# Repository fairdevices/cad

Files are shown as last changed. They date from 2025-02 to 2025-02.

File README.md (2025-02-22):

# Faidevices CAD Repository

The Fairdevices project aims to make household appliances repairable. To achieve this, we are currently developing a universal control board for washing machines that is compatible with as many common devices as possible. This repository manages all source files for the washing machine control and documentation.
Status

## Status

The Project is actively maintained and the development is still in a very early stage. Currently, we are focusing on the development of:

- the power supply
- the heating control

## Licensing

The project is licensed under CERN-OHL-S-2.0. All files can be freely used, modified, and republished. The use of the Fairdevices name and logo is reserved for us.

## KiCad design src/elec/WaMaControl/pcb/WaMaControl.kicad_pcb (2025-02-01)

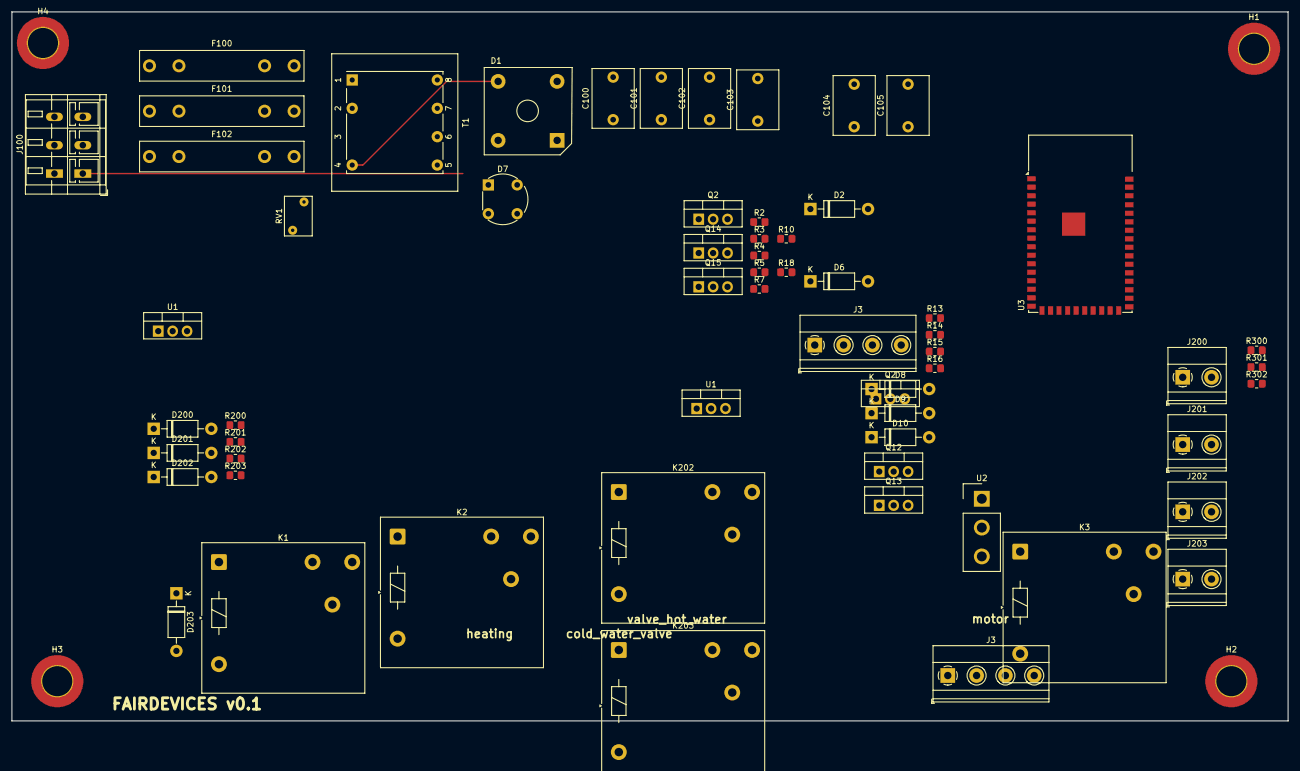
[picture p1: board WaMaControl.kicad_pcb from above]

Board: 2 copper layers, 225.0 x 125.0 mm, 66 parts (0 on the bottom side), 28 nets.

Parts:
C100, C101, C102, C103, C104, C105: C; C_Rect_L10.3mm_W7.2mm_P7.50mm_MKS4
D1: D_Bridge_+-AA; Diode_Bridge_Vishay_KBPC6
D2, D6, D8, D9, D10, D200, D201, D202, D203: 1N4001; D_DO-41_SOD81_P10.16mm_Horizontal
D7: D_Bridge_+-AA; Diode_Bridge_Round_D8.9mm
F100, F101, F102: Fuse; Fuseholder_Littelfuse_445_030_series_5x25mm
H1, H2, H3, H4: MountingHole; MountingHole_5.3mm_M5_DIN965_Pad_TopBottom
J3, J3#2: Conn_01x04_Female; TerminalBlock_Phoenix_MKDS-1,5-4-5.08_1x04_P5.08mm_Horizont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
J100: Conn_01x03_Female; TerminalBlock_WAGO_236-403_1x03_P5.00mm_45Degree
J200, J201, J202, J203: Conn_01x02_Female; TerminalBlock_Phoenix_MKDS-1,5-2-5.08_1x02_P5.08mm_Horizont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
K1, K2: Relay_SPDT; Relay_SPDT_Finder_40.11
K3, K202, K203: AZ850-x; Relay_SPDT_Finder_40.11
Q2, Q2#2, Q12, Q13, Q14: TIC126; TO-220-3_Vertical
Q15: BT138-600; TO-220-3_Vertical
R2, R3, R4, R5, R7, R10, R13, R14, R15, R16, R18, R200, R201, R202, R203, R300, R301, R302: R_Small; R_0805_2012Metric_Pad1.20x1.40mm_HandSolder
RV1: Varistor; RV_Disc_D7mm_W4.9mm_P5mm
T1: Transformer_1P_1S; Transformer_Breve_TEZ-22x24
U1, U1#2: LF50_TO220; TO-220-3_Vertical
U2: logo_fairdevices; Samtec_HPM-03-01-x-S_Straight_1x03_Pitch5.08mm
U3: ESP32-S2-WROVER

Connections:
+3.3V: C104.1, C105.1, R302.1, U1.3 (VO), U1#2.3 (VO), U3.2 (3V3)
+12V: C100.1, C101.1, C102.1, C103.1, D1.1 (+), D2.1 (K), D6.1 (K), D8.1 (K), D9.1 (K), D10.1 (K), D200.1 (K), D201.1 (K), D202.1 (K), D203.1 (K), K1.A1, K2.A1, U1.1 (VI), U1#2.1 (VI)
AC/L: F100.2, K1.14, K2.14, RV1.1, T1.1 (AA)
AC/N: J3.3, J3#2.3, J100.2, J200.2, J201.2, J202.1, RV1.2, T1.2 (AB)
CNTL-coldh2o: R200.1, U3.10 (IO07)
CNTL-drainpump: R203.1, U3.14 (IO11)
CNTL-heating: R202.1, U3.19 (IO16)
CNTR-warmh2o: R201.1, U3.11 (IO08)
Earth_Protective: C100.2, C101.2, C102.2, C103.2, C104.2, C105.2, D1.2 (-), D7.2 (-), J100.1, R10.1, R16.1, R301.2, U1.2 (GND), U1#2.2 (GND), U3.1 (GND), U3.26 (GND), U3.42 (GND), U3.43 (GND)
unnamed: D7.1 (+), R300.1
unnamed: D200.2 (A), K1.A2
unnamed: D201.2 (A), K2.A2
unnamed: F100.1, F101.1, F102.1, J100.3
unnamed: Q2.2 (A), Q2#2.2 (A)
unnamed: Q2.3 (G), Q2#2.3 (G)
unnamed: Q12.2 (A), Q13.1 (K)
unnamed: Q2.1 (K), Q2#2.1 (K), Q14.2 (A)
unnamed: Q15.2 (A2), R4.2
unnamed: Q15.3 (G), R2.1
Trafo-Sek-1: D1.3, D7.3, D7.4, T1.4 (SB)
coldwatervalve2: J200.1, K1.11
freq: R300.2, R301.1, U3.5 (IO02)
heating1: J202.2, Q14.1 (K), Q15.1 (A1), R2.2, R3.1
hotwatervalve2: J201.1, K2.11
motor1: J3.4, J3#2.4, Q12.1 (K)
motorsensor1: J3.2, J3#2.2
motorsensor2: J3.1, J3#2.1
sens_temperature: R302.2, U3.21 (IO18)

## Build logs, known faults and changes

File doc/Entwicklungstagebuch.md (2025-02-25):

# Entwicklungstagebuch WaMa 0.1

[toc]

## Einleitung

Es soll eine universale Waschmaschinen-Steuerung entstehen!

## Lastenheft

- Anschluss: 230V, 16A?
- Steuerspannungen auf Platine: 230V, 3,3V für Arduino

## Komponenten

### Netzteil

Das Netzteil soll im Sinne eines robusten Design aus einem Trafo mit Gleichrichter für die 12-V-Ebene sein. Die 12-V-Ebene versorgt alle Relais mit Spannung.

Verbraucher zur Lastschätzung

| Bauelement | Strom | Leistung |
|:---|---:|---:|
| Kaltwasserventil-Relais | 0,1A | 1W |
| Warmwasserventil-Relais | 0,1A | 1W |
| Relais ? | | |
| ESP 32 | 0,2A | 0,7W |
| P | | 2W? |

Der 12 Vdc-Ebene wird ein Linearregler (500mA) auf 3,3V nachgeschaltet, um die spannungsstabile Energieversorgung des ESP32 zu gewährleisten.

Die Kalt- und Warmwasser-Relais sind schalten nicht gleichzeitig. So lässt sich der Gleichzeitigkeitsfaktor und damit die Bemessungsleistung des Netzteils reduzieren.

Funktionen der Komponenten

SVR100 ... Variator zum Schutz gegen Überspannungen aus dem Netz und die Selbstinduktion beim Ausschalten des Trafos T100

### Temperaturreglung

#### Allgemeines

Die Wassertemperatur wird konventionell durch eine Widerstandsheizung (230V, 2kW, → 10A) realisiert. Die Temperaturmessung erfolgt über ein NTC-Element. Die meisten Waschmaschinen verwenden NTC-Fühler mit einem Widerstand von etwa 4,8kΩ bei 20°C. Wenn in einer bestimmten Waschmaschine ein anderes Modell verwendet wird, dann muss dies entsprechend in der Software für den µC hinterlegt werden.

Die Regelung übernimmt der zentrale µC. Das elektrische Schaltelement ist ein Relais (12V/230).

Verschiedene Schaltelemente haben jeweils ihre Vor- und Nachteile:

**Relais**

* ➕ Vorteile
  * ➕ galvanische Trennung
  * ➕ geringer elektrischer Widerstand → geringere thermische Verluste, keine Kühlung notwendig
  * ➕ geringere Kosten
* ➖ Nachteile
  * ➖ Abbrand an den Schaltelektroden und mögliches Kontaktkleben → vorzeitiger Ausfall

**Triacs**

* ➕ Vorteile
  * ➕ keine mechanisch beweglichen Teile
  * ➕ kein Lichtbogen und damit Alterung
* ➖ Nachteile
  * ➖ hohe thermische Verluste $1\frac{W}{A}$ → Kühlkörper notwendig
  * ➖ keine galvanische Trennung → Optokoppler notwendig

Aufgrund des Entwicklungsziels einer möglichst hohen Langlebigkeit wird sich für den Einsatz eines Triacs entschieden. Die $10W$ Verluste bei einem Strom von $10A$ entsprechen vertretbaren $\frac{10W}{2000W} = 0,5\%$ Verlustleistung. Ein ausreichend großer Kühlkörper wird durch Versuche ermittelt.

#### Randbedingungen für Regelung

Wasservolumen, geschätzt, $10-25L$

Wärmekapazität Wasser: $4,19 kJ/(kg K)$

Worst case: 90-°C-Wäsche, dT = 80K, 10..25kg → 30...60min Heizphase ohne Thermische Verluste

Regelung mit Relais: EIN-Schaltdauer im Bereich von Minuten, 2-Punkt-Regelung mit ±2°C ausreichend

Regelung mit Thyristor: Ein-Schaltdauer funktionsbedingt 2 Sinus-Halbwellen = 20ms, jede Periode müssten die Thyristoren neu getriggert werden.

### Motorsteuerung

### Magnetventile für Kalt- und Warmwasser

Elektrische Kenndaten für Ventile: 230V, xxx? A

```math
f_g = \frac{ 0,35 }{ 30MHz }
```

## Fehlererkennungsstrategien

Ähnlich wie in aktuellen PKW, die einem sagen, dass die hintere rechte Bremsleuchte defekt ist, sollte die Steuerung sich selbst überprüfen und Fehler in den angesteuerten Komponenten erkennen können.

### Dämpfer

Waschtrommel ist eine Feder-Masse-Schwinger → Eigenfrequenz → ist eine entsprechende Stromharmonische im Motorstrom zu hoch, dann Dämpfer verschlissen.

### Hauptlager

Akustische Signal bzw. Körperschall sollten sich detektieren lassen.

### Heizung

Kein Strom, dann Sicherung raus, weil Schluss gegen Masse

### Motor / Laugenpumpe

Kein Strom, dann Bürsten defekt?

## Fragen

- 12V vs 24V bei den Relais?
- ESP32 vs Arduino?
- Relais vs Thyristoren vs SSR?

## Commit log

2025-02-01 - migration of development files from 09-11-24
    [WaMaControl.kicad_pcb, WaMaControl.kicad_sch, heating-motor-valves.kicad_sch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]
2025-02-01 - migration of development files from 01-02-25
    [WaMaControl.kicad_pcb, WaMaControl.kicad_sch, heating-motor-valves.kicad_sch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]
